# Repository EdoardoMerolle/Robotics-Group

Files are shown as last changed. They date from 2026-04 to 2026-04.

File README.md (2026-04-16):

# Connect 4 Robot Project

This repository contains the Connect 4 AI, webcam-based board detection, and gantry serial control used to play on a physical board.

## What You Need

### Required Project Files

To run the webcam version from `run_connect4_windows_webcam.bat`, these local files are required:

- `run_connect4_windows_webcam.bat`
- `connect4_webcam.py`
- `main.py`
- `gantry_serial.py`
- `requirements.txt`

### Python Packages

Install the packages listed in `requirements.txt`:

- `numpy`
- `opencv-python`
- `pyserial`

### Optional Files

These files are useful for testing or other modes, but they are not required for the webcam launcher:

- `connect4_ai_test.py`
- `connect4_serial_test.py`
- `vex_column_test.py`
- `run_connect4_windows.bat`
- `run_connect4.sh`
- `aits.md`
- `Assessment 2.docx`
- `.3mf` files
- `STL FILES/`

### Hardware and Runtime Requirements

- A working webcam
- A graphical desktop session
- If you want serial output to the robot/brain: a connected serial device and the correct COM port

## How To Run

### Windows Webcam Mode

Run:

```bat
run_connect4_windows_webcam.bat
```

You can also pass a COM port and baud rate:

```bat
run_connect4_windows_webcam.bat COM4 115200
```

If no arguments are provided, the script defaults to:

- COM port: `COM4`
- Baud rate: `115200`

### What the Batch File Does

The batch file:

- finds the Python interpreter
- enables serial output through environment variables
- starts `connect4_webcam.py`

## Setup

### Physical Setup

- Board location: Place the board on a flat, stable surface with a plain background behind it.
- Webcam position: Position the webcam so it faces the board directly and captures the full play area.
- Lighting setup: Use bright, even lighting to reduce colour detection errors and shadows.
- Gantry placement: Keep the dropper chute just above and parallel to the board so pieces can be placed cleanly.
- Serial connection port: Use the correct COM port for your setup. `COM4` is the default, but you can change it as explained in the [How To Run](#how-to-run) section.

### Calibration Steps

1. Open the webcam mode.
2. Click on the four corner holes of the board to calibrate the warped camera view.
3. Sample the human counter colour by clicking on a human counter in the Board View and pressing `H`.
4. To sample the program counter colour, repeat the same step but press `A` instead.
5. Check that the detected board matches the real board.
6. Adjust the calibration if needed.

### Game Start Procedure

- Who moves first: Human
- How a human move is entered: Physically place the counter into the desired column on the board.
- How the AI move is displayed or sent to the gantry: The program displays the suggested column and sends the column number through serial connection.
- What to do if the board state becomes inconsistent: Press `R` on your keyboard to reset the calibration and game state.

### Notes for Demonstration
- Best lighting conditions: Bright and even

## Notes

- `connect4_webcam.py` imports `main.py` for the Connect 4 game logic.
- `connect4_webcam.py` imports `gantry_serial.py` for optional serial communication.
- The webcam mode calibrates the board from the four corner holes, warps the camera into a top-down view, and then tracks moves using colour calibration and board-state validation.
- If the board detection becomes inconsistent, the program shows debug overlays and lets you recalibrate the board or reset the full session with `r`.
- The gantry side uses serial column commands and includes a calibration workflow so the column positions can be tuned for the physical build.
- If `pyserial` is missing, the webcam mode can still run, but serial commands to the robot will be disabled.
- If OpenCV or NumPy is missing, webcam mode will not start.

## Other Run Modes

If you only want to test the AI without the webcam, use:

```bat
python connect4_ai_test.py
```

## Repository Contents

- `main.py`: Connect 4 rules, board handling, and AI search
- `connect4_webcam.py`: webcam detection and physical board gameplay
- `gantry_serial.py`: serial link to the robot/brain
- `connect4_ai_test.py`: terminal-based AI test mode
- `connect4_serial_test.py`: serial communication test
- `vex_column_test.py`: gantry calibration/testing utility

## References

- OpenCV documentation: https://docs.opencv.org/
- NumPy documentation: https://numpy.org/doc/
- pyserial documentation: https://pyserial.readthedocs.io/
- VEX EXP documentation and support resources used during development
- AI transparency statement and usage summary: `AITS.md`

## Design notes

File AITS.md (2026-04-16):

# Group 9 AITS Statement

- Model used: ChatGPT 5 Codex
- AITS level: 5

I used AI throughout this project to refine the Connect 4 robot system, including the game logic, webcam-based board detection, and gantry control. The Connect 4 logic in `main.py` was my own Level 5 work, and Codex helped extend it by improving the minimax-based decision-making, move ordering, threat detection, and physical-game integration. For the rest of the system, I directed the AI to generate code, reviewed the results, tested them on the physical setup, and asked for changes whenever the behaviour was not correct or not reliable enough for the real board.

Codex then helped refine the Connect 4 behaviour, including the minimax-based decision-making, move ordering, threat detection, and win/block logic. I tested those outputs and requested adjustments to make the AI play more sensibly and to improve how it handled edge cases during actual gameplay.

Codex was also used to build the webcam pipeline for detecting the physical board. This included perspective correction, colour calibration, board-state reconstruction, detection stability checks, and validation of legal board positions. I checked the webcam output against the physical board, identified problems such as unreliable move detection, incorrect board cropping, camera-index failures, and gravity-check errors, and then asked for revisions until the system behaved properly.

For the hardware side, Codex generated the VEX EXP gantry control and serial communication code. I tested how the brain responded to column commands, checked that the gantry moved to the correct positions, and requested changes such as slower motion, a pause at the selected column, and a column position calibration mode. I also verified that the system could recover from serial and controller issues during testing.

My role was to direct ChatGPT Codex, judge whether the results were acceptable, and keep iterating until the final system worked as a complete physical computing project. The final submission is therefore based on my own Connect 4 logic, with AI-assisted webcam-controlled functionality and serial connection, human testing, and iterative correction throughout, which is why I consider it to fit AITS level 5.

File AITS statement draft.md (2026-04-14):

# Group 9 AITS Statement

- Model used: ChatGPT 5 Codex
- AITS level: 5

I used AI throughout this project to refine the Connect 4 robot system, including the game logic, webcam-based board detection, and gantry control. The Connect 4 logic in `main.py` was my own Level 5 work, and Codex helped extend it by improving the minimax-based decision-making, move ordering, threat detection, and physical-game integration. For the rest of the system, I directed the AI to generate code, reviewed the results, tested them on the physical setup, and asked for changes whenever the behaviour was not correct or not reliable enough for the real board.

The AI then helped refine the Connect 4 behaviour, including the minimax-based decision-making, move ordering, threat detection, and win/block logic. I tested those outputs and requested adjustments to make the AI play more sensibly and to improve how it handled edge cases during actual gameplay.

AI was also used to build the webcam pipeline for detecting the physical board. This included perspective correction, colour calibration, board-state reconstruction, detection stability checks, and validation of legal board positions. I checked the webcam output against the physical board, identified problems such as unreliable move detection, incorrect board cropping, camera-index failures, and gravity-check errors, and then asked for revisions until the system behaved properly.

For the hardware side, AI generated the VEX EXP gantry control and serial communication code. I tested how the brain responded to column commands, checked that the gantry moved to the correct positions, and requested changes such as slower motion, a pause at the selected column, and a clearer calibration workflow. I also verified that the system could recover from serial and controller issues during testing.

My role was to direct the AI, judge whether the results were acceptable, and keep iterating until the final system worked as a complete physical computing project. The final submission is therefore based on my own Connect 4 logic, with AI-assisted refinement, human testing, and iterative correction throughout, which is why I consider it to fit AITS level 5.

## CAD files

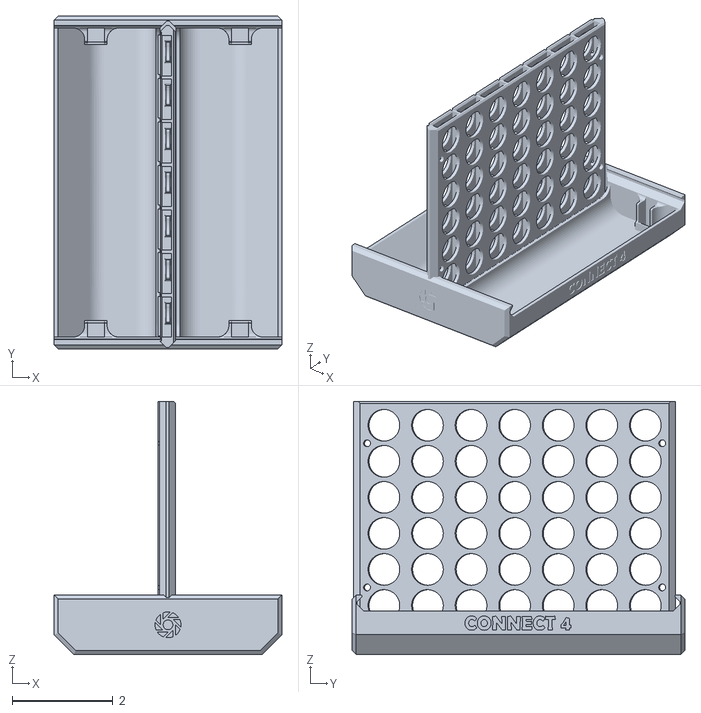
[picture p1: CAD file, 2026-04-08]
STL FILES/Connect 4 Assembled.stl
4.53 x 6.61 x 5.03

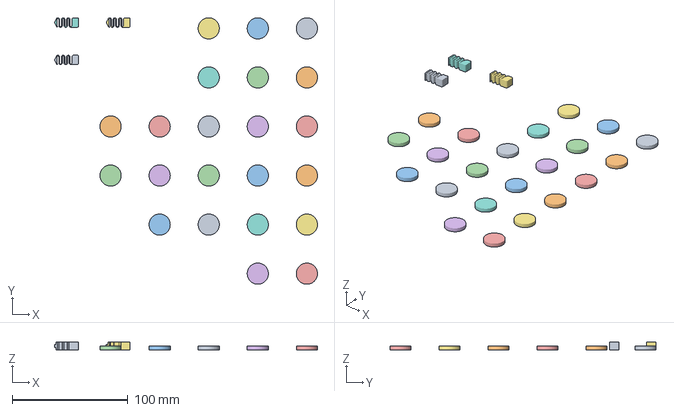
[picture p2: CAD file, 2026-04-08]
Bambu Files/coins.3mf
226.8 x 229.8 x 6.80 mm
blank token stl.stl x 22
spring stl.stl x 3

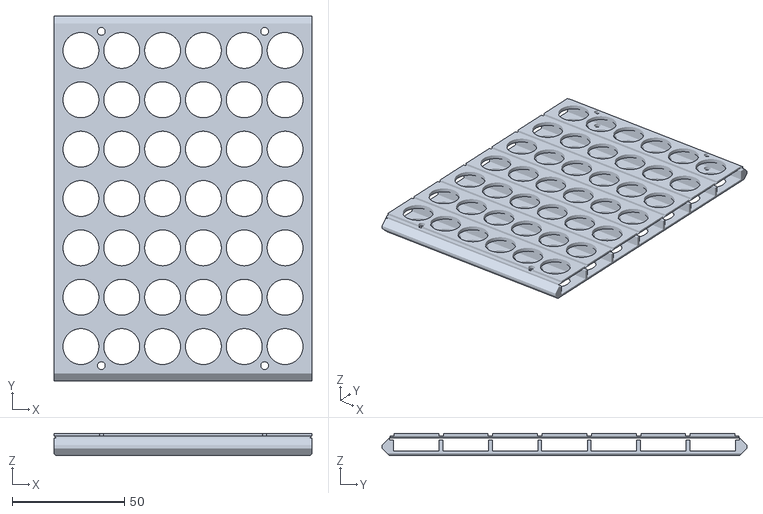
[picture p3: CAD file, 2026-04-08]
STL FILES/Board.stl
115.0 x 162.6 x 10.0

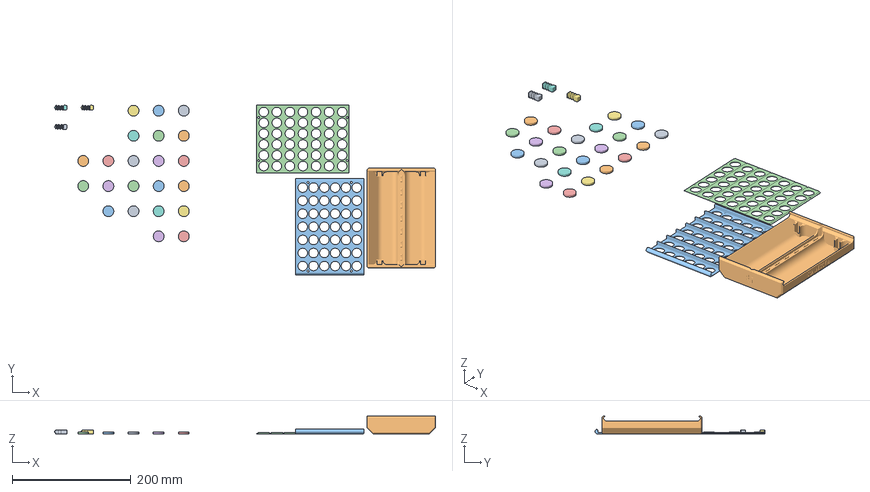
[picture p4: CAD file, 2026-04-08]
Bambu Files/connect_4_four_in_a_row_classic_portable_tokens_scaled_at_99_percent(2).3mf
641.3 x 286.6 x 30.0 mm
blank token stl.stl x 22
spring stl.stl x 3
case clasic stl.stl
lidb horizontal
lida horizontal

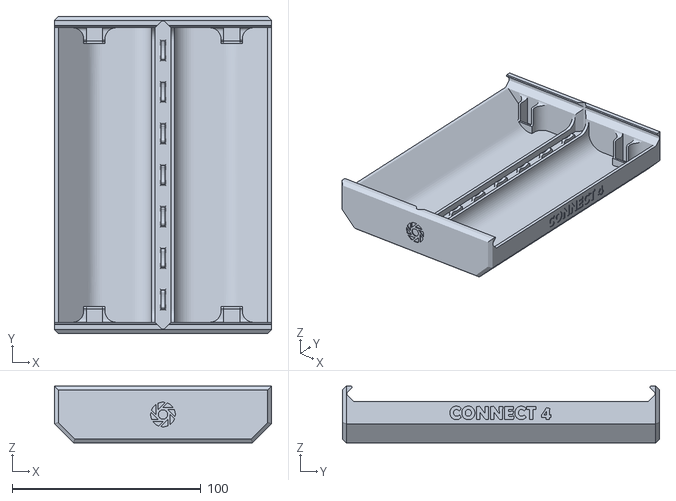
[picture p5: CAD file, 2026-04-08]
STL FILES/Case.stl
115.0 x 168.0 x 30.0

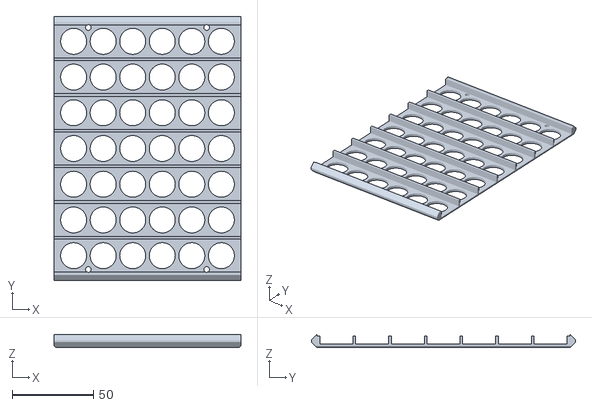
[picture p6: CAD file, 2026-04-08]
STL FILES/lidb horizontal.stl
115.0 x 162.6 x 8.00

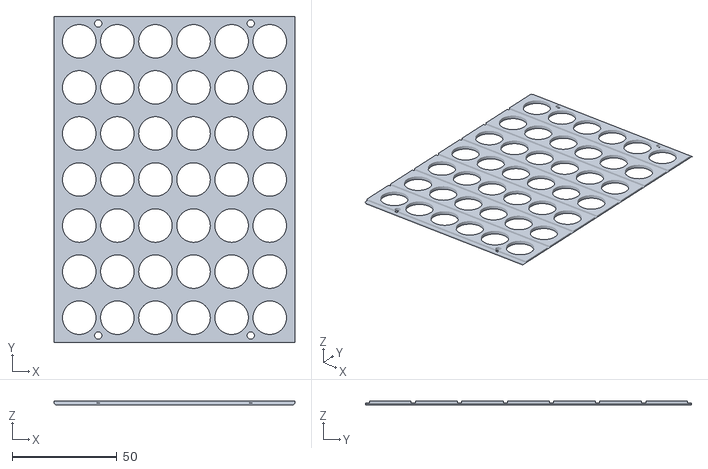
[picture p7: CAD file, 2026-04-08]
STL FILES/lida horizontal.stl
115.0 x 155.7 x 2.00

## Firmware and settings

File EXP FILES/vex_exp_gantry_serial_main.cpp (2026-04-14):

/*----------------------------------------------------------------------------*/
/*                                                                            */
/*    File: vex_exp_gantry_serial_main.cpp                                    */
/*    Target: VEX EXP Brain                                                   */
/*                                                                            */
/*    Paste this into a new VEXcode C++ project and download it to the brain. */
/*                                                                            */
/*    Serial protocol: send one line containing a column number 1-7.          */
/*    Example messages from the AI computer:                                  */
/*      1                                                                      */
/*      4                                                                      */
/*      7                                                                      */
/*                                                                            */
/*    The brain reads that number, then moves the gantry motor to the preset  */
/*    position for that column. Adjust COLUMN_POSITIONS_DEG to match your      */
/*    real gantry spacing.                                                     */
/*                                                                            */
/*----------------------------------------------------------------------------*/

#include "vex.h"
#include <cstdio>
#include <cstdlib>
#include <cmath>

using namespace vex;

brain Brain;
motor GantryMotor = motor(PORT1, ratio18_1, false);
controller Controller1 = controller(primary);

const int COLUMN_COUNT = 7;
const int HOME_COLUMN = 0;
const int MOTOR_SPEED_PCT = 10;
const int CALIBRATION_JOG_SPEED_PCT = 5;
const int COLUMN_DWELL_MS = 5000;
const double JOG_DEADBAND_PCT = 5.0;
double homePositionDeg = -90.0;
double columnPositionsDeg[COLUMN_COUNT] = {
  0.0,   // Column 1
  90.0,  // Column 2
  180.0, // Column 3
  270.0, // Column 4
  360.0, // Column 5
  450.0, // Column 6
  540.0  // Column 7
};

volatile int pendingSerialColumn = 0;
volatile bool serialCommandPending = false;

void drawStatus(const char *line1, const char *line2 = "") {
  Brain.Screen.clearScreen();
  Brain.Screen.setCursor(2, 1);
  Brain.Screen.print("Gantry");
  Brain.Screen.setCursor(4, 1);
  Brain.Screen.print(line1);
  Brain.Screen.setCursor(6, 1);
  Brain.Screen.print(line2);
}

void drawCalibrationScreen(int selectedColumn) {
  Brain.Screen.clearScreen();
  Brain.Screen.setCursor(1, 1);
  Brain.Screen.print("Cal");
  Brain.Screen.setCursor(3, 1);
  Brain.Screen.print("Col: %d", selectedColumn);
  Brain.Screen.setCursor(4, 1);
  Brain.Screen.print("Deg: %.1f", GantryMotor.position(degrees));
  Brain.Screen.setCursor(6, 1);
  Brain.Screen.print("Stick: jog");
  Brain.Screen.setCursor(7, 1);
  Brain.Screen.print("A save U/D sel");
  Brain.Screen.setCursor(8, 1);
  Brain.Screen.print("R1 done B cal");
}

void printCalibrationTable() {
  printf("CAL ");
  printf("%d=%.1f ", HOME_COLUMN, homePositionDeg);
  for (int index = 0; index < COLUMN_COUNT; ++index) {
    printf("%d=%.1f ", index + 1, columnPositionsDeg[index]);
  }
  printf("\n");
}

void printCalibrationStatus(int selectedColumn) {
  printf(
    "CAL_STATUS selected=%d motor_deg=%.1f save=A select=UpDown finish=R1 enter=B\n",
    selectedColumn,
    GantryMotor.position(degrees)
  );
}

void moveToStoredHome() {
  GantryMotor.spinToPosition(homePositionDeg, degrees, MOTOR_SPEED_PCT, velocityUnits::pct, true);
}

void runCalibrationMode() {
  // Manual calibration mode lets you jog the gantry and save positions.
  int selectedColumn = HOME_COLUMN;
  bool wasUpPressed = false;
  bool wasDownPressed = false;
  bool wasAPressed = false;
  bool wasR1Pressed = false;
  int lastPrintedColumn = -1;
  double lastPrintedPosition = 1000000.0;

  GantryMotor.stop(hold);
  printf("CAL_MODE entered\n");
  printCalibrationStatus(selectedColumn);

  while (true) {
    double axisPercent = Controller1.Axis3.position(percentUnits::pct);
    if (std::fabs(axisPercent) <= JOG_DEADBAND_PCT) {
      axisPercent = 0.0;
    }

    if (axisPercent == 0.0) {
      GantryMotor.stop(hold);
    } else {
      double commandPercent = axisPercent > 0 ? CALIBRATION_JOG_SPEED_PCT : -CALIBRATION_JOG_SPEED_PCT;
      GantryMotor.spin(directionType::fwd, commandPercent, velocityUnits::pct);
    }

    bool upPressed = Controller1.ButtonUp.pressing();
    bool downPressed = Controller1.ButtonDown.pressing();
    bool aPressed = Controller1.ButtonA.pressing();
    bool r1Pressed = Controller1.ButtonR1.pressing();

    if (upPressed && !wasUpPressed && selectedColumn < COLUMN_COUNT) {
      selectedColumn += 1;
      printCalibrationStatus(selectedColumn);
    }

    if (downPressed && !wasDownPressed && selectedColumn > HOME_COLUMN) {
      selectedColumn -= 1;
      printCalibrationStatus(selectedColumn);
    }

    if (aPressed && !wasAPressed) {
      double currentPosition = GantryMotor.position(degrees);
      if (selectedColumn == HOME_COLUMN) {
        homePositionDeg = currentPosition;
      } else {
        columnPositionsDeg[selectedColumn - 1] = currentPosition;
      }
      printf("CAL_SAVED column=%d position=%.1f\n", selectedColumn, currentPosition);
      printCalibrationTable();
    }

    if (r1Pressed && !wasR1Pressed) {
      GantryMotor.stop(hold);
      moveToStoredHome();
      drawStatus("Cal saved", "Serial on");
      printf("CAL_MODE finished\n");
      printCalibrationTable();
      wait(600, msec);
      return;
    }

    wasUpPressed = upPressed;
    wasDownPressed = downPressed;
    wasAPressed = aPressed;
    wasR1Pressed = r1Pressed;

    double currentPosition = GantryMotor.position(degrees);
    if (selectedColumn != lastPrintedColumn || std::fabs(currentPosition - lastPrintedPosition) >= 5.0) {
      printCalibrationStatus(selectedColumn);
      lastPrintedColumn = selectedColumn;
      lastPrintedPosition = currentPosition;
    }

    drawCalibrationScreen(selectedColumn);
    wait(20, msec);
  }
}

void moveToColumn(int columnNumber) {
  // Move to the requested column, pause, then return home.
  if (columnNumber < 1 || columnNumber > COLUMN_COUNT) {
    drawStatus("Invalid column", "Expected 1 to 7");
    printf("ERR Invalid column %d\n", columnNumber);
    return;
  }

  double targetDegrees = columnPositionsDeg[columnNumber - 1];
  char statusLine[32];
  snprintf(statusLine, sizeof(statusLine), "Moving to column %d", columnNumber);
  drawStatus(statusLine, "Motor running...");

  GantryMotor.spinToPosition(targetDegrees, degrees, MOTOR_SPEED_PCT, velocityUnits::pct, true);

  char completeLine[32];
  snprintf(completeLine, sizeof(completeLine), "At column %d", columnNumber);
  drawStatus(completeLine, "Wait 5 sec");
  printf("OK %d\n", columnNumber);
  wait(COLUMN_DWELL_MS, msec);

  drawStatus("Return home", "Motor running");
  moveToStoredHome();

  drawStatus("Home: col 0", "Serial wait");
}

int serialReaderTask() {
  // Read newline-terminated column commands from stdin.
  while (true) {
    char inputBuffer[16];
    if (fgets(inputBuffer, sizeof(inputBuffer), stdin) != NULL) {
      int requestedColumn = atoi(inputBuffer);
      if (requestedColumn >= 1 && requestedColumn <= COLUMN_COUNT) {
        pendingSerialColumn = requestedColumn;
        serialCommandPending = true;
      } else {
        printf("ERR Invalid column %d\n", requestedColumn);
      }
    }
    wait(20, msec);
  }
  return 0;
}

int main() {
  // Home the gantry, start the reader thread, then wait for commands.
  GantryMotor.setStopping(hold);
  GantryMotor.setVelocity(MOTOR_SPEED_PCT, percent);
  GantryMotor.resetPosition();

  moveToStoredHome();
  drawStatus("Home: col 0", "Send 1-7");
  printf("READY\n");
  printCalibrationTable();
  thread serialThread = thread(serialReaderTask);

  while (true) {
    if (Controller1.ButtonB.pressing()) {
      while (Controller1.ButtonB.pressing()) {
        wait(20, msec);
      }
      runCalibrationMode();
      drawStatus("Home: col 0", "Send 1-7");
    }

    if (serialCommandPending) {
      int requestedColumn = pendingSerialColumn;
      serialCommandPending = false;
      moveToColumn(requestedColumn);
    }

    wait(20, msec);
  }
}

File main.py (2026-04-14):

import os
import random
import time
import csv

# Game state shared by the terminal and webcam modes.
gameOver = False
board = []
symbol1 = "●"
symbol2 = "○"
rows = 6
cols = 7

# Minimax metrics used by the evaluation helper.
nodesExpanded = 0
maxDepthReached = 0
pruneCount = 0
branchCounts = []

# Console helpers
def ClearConsole():
    if os.name == "nt":
        os.system("cls")
    else:
        os.system("clear")

def CreateBoard():
    global board
    for _ in range(rows):
        row = [" "] * cols
        board.append(row)

def PrintBoard():
    ClearConsole()

    for row in board:
        print("|", end=" ")
        for cell in row:
            print(cell, end=" | ")
        print()

    print(" ", end="")
    for i in range(len(board[0])):
        # Keep the column numbers aligned under the board.
        print(f" {i+1}  ", end="")  
    print()

# Move helpers
def PlaceCounter(pos, symbol):
    global board

    availableRow = None
    for row in range(len(board) - 1, -1, -1):
        if board[row][pos - 1] == " ":
            availableRow = row
            break

    if availableRow is not None:
        board[availableRow][pos - 1] = symbol
        PrintBoard()
        return "Successful"
    else:
        print("Column is full!")
        return "Failed"

def PlayerTurn():
    symbol = symbol1
    selected = False

    while not selected:
        try:
            colPosition = int(input(f"\nSelect a Column (1 - 7): "))
            if 1 <= colPosition <= 7 and PlaceCounter(colPosition, symbol) == "Successful":
                selected = True
            else:
                print("Column must be between 1 and 7")
        except ValueError:
            print("Invalid input. Please enter a number between 1 and 7")

def AgentTurn(choice, agentNumber):
    if agentNumber != None:
        symbol = symbol1 if agentNumber == 1 else symbol2
    else:
        symbol = symbol2

    match choice:
        case 1:
            col = RandomAgentMove(board)
        case 2:
            col = RuleBasedAgent(board)
        case 3:
            col = BestMove(board, symbol2, symbol1)

    PlaceCounter(col + 1, symbol)


def GetAvailableCols(board):
    return [col for col in range(cols) if board[0][col] == " "]

def IsFull(board):
    return all(board[0][col] != " " for col in range(cols))

def GetAvailableRow(board, col):
    for row in range(rows - 1, -1, -1):
        if board[row][col] == " ":
            return row
    return None

def ApplyMove(board, col, symbol):
    tempBoard = [row[:] for row in board]
    row = GetAvailableRow(tempBoard, col)
    if row is None:
        return None
    tempBoard[row][col] = symbol
    return tempBoard

# Prefer the centre first, then work outward.
def OrderedCols(board):
    center = cols // 2
    return sorted(GetAvailableCols(board), key=lambda col: (abs(col - center), col))

def GetWinningMoves(board, symbol):
    winningMoves = []
    for col in GetAvailableCols(board):
        tempBoard = ApplyMove(board, col, symbol)
        if tempBoard is not None and IsWinningBoard(symbol, tempBoard):
            winningMoves.append(col)
    return winningMoves

def IsWinningBoard(symbol, board):
    # Horizontal check.
    for r in range(rows):
        count = 0
        for c in range(cols):
            count = count + 1 if board[r][c] == symbol else 0
            if count == 4:
                return True
    # Vertical check.
    for c in range(cols):
        count = 0
        for r in range(rows):
            count = count + 1 if board[r][c] == symbol else 0
            if count == 4:
                return True
    # Diagonal \ check.
    for r in range(rows - 3):
        for c in range(cols - 3):
            if (board[r][c] == symbol and
                board[r + 1][c + 1] == symbol and
                board[r + 2][c + 2] == symbol and
                board[r + 3][c + 3] == symbol):
                return True
    # Diagonal / check.
    for r in range(3, rows):
        for c in range(cols - 3):
            if (board[r][c] == symbol and
                board[r - 1][c + 1] == symbol and
                board[r - 2][c + 2] == symbol and
                board[r - 3][c + 3] == symbol):
                return True
    return False

def GetWinPattern(symbol, board):
    # Match the win shape for the metrics CSV.
    for r in range(rows):
        count = 0
        for c in range(cols):
            count = count + 1 if board[r][c] == symbol else 0
            if count == 4:
                return "horizontal"
            
    # Vertical
    for c in range(cols):
        count = 0
        for r in range(rows):
            count = count + 1 if board[r][c] == symbol else 0
            if count == 4:
                return "vertical"
            
    # Diagonal \
    for r in range(rows - 3):
        for c in range(cols - 3):
            if (board[r][c] == symbol and
                board[r + 1][c + 1] == symbol and
                board[r + 2][c + 2] == symbol and
                board[r + 3][c + 3] == symbol):
                return "diagonal_\\"
            
    # Diagonal /
    for r in range(3, rows):
        for c in range(cols - 3):
            if (board[r][c] == symbol and
                board[r - 1][c + 1] == symbol and
                board[r - 2][c + 2] == symbol and
                board[r - 3][c + 3] == symbol):
                return "diagonal_/"
    return False

def PrintWin(symbol, board, isAgentGame):
    if isAgentGame == True:
        playerName = "Agent 1" if symbol == symbol1 else "Agent 2"
    else:
        playerName = "Player" if symbol == symbol1 else "Agent"

    if IsWinningBoard(symbol, board):
        print(f"{playerName} wins")
        return True

    if IsFull(board):
        print("It's a draw!")
        return True

    return False

def RandomAgentMove(board):
    # Picks out of a random column that is available
    return random.choice(GetAvailableCols(board))

def RuleBasedAgent(board):
    # Creates a temporary board to check whether a move from either itself or the opponent will win
    # Based on this will decide on trying to win or to block the opponent from winning

    # Try to win
    for col in OrderedCols(board):
        tempBoard = ApplyMove(board, col, symbol2)
        if IsWinningBoard(symbol2, tempBoard):
            return col

    # Try to block
    for col in OrderedCols(board):
        tempBoard = ApplyMove(board, col, symbol1)
        if IsWinningBoard(symbol1, tempBoard):
            return col

    # Else
    return random.choice(OrderedCols(board))
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
